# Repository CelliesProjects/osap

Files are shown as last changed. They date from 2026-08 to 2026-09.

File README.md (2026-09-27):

# OS Audio Player

ESP32 + VS1053 based network and SD audio player with a responsive web interface.

A very capable audio player with:

* MP3, M4A, AAC, OGG, and 16-bit FLAC playback
* Playlist queue for 100 items
* WebSocket based live UI
* A very fast **caching** SD card filebrowser
* Radio presets 
* Automatic adding of premium/private channels during build
* Internet radio search with [radio-browser.info](https://www.radio-browser.info/)
* Favorites system
* Mobile friendly interface

## OSAP UI video

https://github.com/user-attachments/assets/1be9de44-ba12-41da-8240-82e3cfe4a38c

## Finished player

assembled case

# Required hardware

Minimal component count, development is done on the following hardware:

* [7x9 cm prototype board](https://aliexpress.com/item/1005007977006793.html)
* [WEMOS S3 MINI](https://www.wemos.cc/en/latest/s3/s3_mini.html)
* [WEMOS Micro SD card shield](https://www.wemos.cc/en/latest/d1_mini_shield/micro_sd.html)
* [Adafruit VS1053 Codec + MicroSD Breakout](https://www.adafruit.com/product/1381)
* Optional [Adafruit 1.3" I²C OLED](https://www.adafruit.com/product/938) status indicator
* To connect the OLED a [STEMMA QT header cable](https://www.adafruit.com/product/4209)
* Web browser as main UI

The hardware listed above is the development/reference setup used for OSAP.  
Other ESP32-S3 boards, SD card interfaces and VS1053-based audio hardware may also be suitable.  
The software is not inherently tied to the specific boards listed here.

The reference player is build on the above 7x9 cm prototype board that fits the cases in the `stl` folder.

## Optional status indicator

An optional [Adafruit 1.3" I²C OLED display](https://www.adafruit.com/product/938) can be added for device status information.  

It displays boot progress, connection status and the current IP address.  

**Note:** To keep the player unobtrusive and power efficient, the OLED automatically sleeps after startup.  
Wake-up is performed using a capacitive touch input, which can be as simple as a GPIO connected to a metal button, screw head or other exposed conductive surface.

## SPI Configuration Notes

The current implementation assumes dedicated SPI buses for SD card and VS1053 access.  
Shared SPI configurations may compile, partially function, fully function or fail in creative and confusing ways.

Dedicated SPI wiring is the recommended and supported configuration.

---

# Features

## Privacy first

* No accounts
* No telemetry
* No phone app install
* No ads
* No “smart platform”
* Just a websocket UI on your LAN

## Audio 

* VS1053 hardware decoder with MP3, M4A, AAC, OGG and FLAC decoding
* Local SD playback
* Internet radio streaming
* Playlist queue system
* Favorites saving/loading
* Playback state synchronization between UI clients

## Web Interface

* Clean UI optimized for mobile use
* Responsive split-pane layout
* Works on all modern browsers
* Touch friendly controls
* Search interface for radio stations
* Overlay "now playing" mode
* Toast notifications and errors
* Very fast caching file browser

### Multiple WiFi networks supported

The player can be configured with multiple WiFi networks and automatically connects to the strongest available known network.  
This allows the same device to be used with different network setups such as a home network and a mobile phone hotspot without requiring reconfiguration.

## UI Performance

Multiple simultaneous clients are supported and kept in sync with the player state.  
SD requests are quite expensive and are handled async and cached to keep the UI responsive.  

- File browser requests are cached if the response takes more than 100 ms to build.  
- The favorites folder is cached on every mutation.  

---

# Download and initial setup

The following steps assume you already have a working VSCode/PlatformIO setup.

1. [Click here](https://github.com/CelliesProjects/osap/releases/latest) to go to the latest release page.  
On the release page, click on `Source code (zip)` then download and unzip this file.  

2. Open VSCode and select from the top menu `File->Open folder` then select the folder where you unzipped the repository to.  
This is the project folder.

3. Provide your wifi secrets by creating the file `src/secrets.hpp` in the project folder.  
See the [Building](#building) section below on how to format this file.

4. Open PlatformIO and select `Project tasks->develop->Upload and monitor`.  

PlatformIO will download and install all the assets that are needed to build the player firmware.  
This might take a while depending on your internet speed and computer capabilities.  
If all assets are installed, PlatformIO will start compiling and flash your player.

**Note:** The first time you build this project, a lot of files will be downloaded and then compiled which might take a long time.  

---

# Building the firmware

## Required secrets file

Before compiling create a new file with your WiFi and location secrets:

`src/secrets.hpp`

Use this example setup as a template:

```cpp
#pragma once

struct Secret
{
    const char *SSID;
    const char *PSK;
};

/* OSAP will connect to the strongest available network */
constexpr Secret networks[] =
    {
        {"network1", "password"},
        {"network2", "password"},
    };

/* Central European Time - see:
     https://github.com/nayarsystems/posix_tz_db/blob/master/zones.csv */
const char *TIMEZONE = "CET-1CEST,M3.5.0,M10.5.0/3";

/* Replace "nl" with your own country code:
    https://en.wikipedia.org/wiki/ISO_3166-2#Current_codes */
const char *NTP_POOL = "nl.pool.ntp.org";

/* Optional custom mDNS hostname */
//#define OSAP_HOSTNAME "music-player"
```

## Preset radio stations setup

Preset radio stations are defined in `src/presets.hpp`.

## Optional: adding private presets

Adding private or premium radio presets is very easy.

Place one or more `.pls` playlist files in the project root before compiling.  

During build:

* `.pls` files are automatically parsed
* presets are generated and merged into the main preset list

The added `.pls` files are ignored by git.

---

# Using the player

The web UI consists of two panes.  
A selectable source tab on the left and a playlist tab on the right.  

There are 4 source tabs, `library`, `presets`, `favorites` and `search`.

Click on a tab button to show a tab.

## Using the SD card library

You will need a FAT32 formatted micro SD card.  

Folders are navigated by clicking.

Single files can be added by clicking on the file or added and started with the **play** button.

Folders can be scanned and all found items added by clicking the **play** button.  

This will add all files in a folder and start playing the first added item if nothing is playing.  

## Favorites

Internet radio stations found through the search interface can be saved as favorites.

Favorites are stored on the SD card in the `/.favorites` folder.

Saved favorites can be inspected by visiting `http://player-ip/favorites` in a browser.

The generated files are formatted so they can easily be copied into `src/presets.hpp` if you want to make them permanent presets.

## Searching for radio stations

You can search for radio stations on [radio-browser.info](https://www.radio-browser.info/) with the search bar.  

Search results are displayed in the search tab.

## Now Playing overlay

The **Info** button at the bottom of the page toggles the *Now Playing* overlay.

The overlay shows the currently playing station or track and playback progress.  
After 30 seconds no activity the overlay is show automatically.  

When an Internet radio station originating from the search results is playing, a **Save as Favorite** button becomes available, allowing the station to be stored on the SD.

# Used Libraries / Components

## ESP32 C++ backend

These libraries are used internally by the player:

* HTTP traffic and WebSocket UI messaging are handled by [PsychicHttp](https://github.com/hoeken/PsychicHttp) webserver library - [MIT](https://github.com/hoeken/PsychicHttp?tab=MIT-1-ov-file)
* Audio playback is handled by [ESP32_VS1053_Stream](https://github.com/CelliesProjects/ESP32_VS1053_Stream) library - [MIT](https://github.com/CelliesProjects/ESP32_VS1053_Stream?tab=MIT-1-ov-file)
* Low level codec access is handled by [ESP_VS1053_Library](https://github.com/baldram/ESP_VS1053_Library) - [GPL-3.0](https://github.com/baldram/ESP_VS1053_Library?tab=GPL-3.0-1-ov-file)
* The OLED is handled by [Adafruit SSD1306 library](https://github.com/adafruit/Adafruit_SSD1306) - [BSD](https://github.com/adafruit/Adafruit_SSD1306?tab=License-1-ov-file)

## WebUI frontend

All frontend resources are compiled into the player UI:

* Vanilla HTML/CSS/JavaScript is used for the interface and application logic
* SVG icons from Google Fonts are inlined into the generated HTML during build - [Apache 2.0](https://github.com/google/material-design-icons?tab=Apache-2.0-1-ov-file#readme)
* [Reconnecting WebSocket](https://github.com/joewalnes/reconnecting-websocket) is included (minified) in the UI - [MIT](https://github.com/joewalnes/reconnecting-websocket?tab=MIT-1-ov-file)

---

# Building the hardware

Most of the required parts.  

parts

To stack the SD board on top of the CPU board, 3 pieces of [8 pin single row headers](https://aliexpress.com/item/1005011936791979.html) are required.

Also an additional countersunk M6 20-25mm long bolt with a fitting nut and a cable lug are required to build the example cases.

---

Possible parts layout, this layout will fit the cases in the `stl` folder and both cables and SD card are accesible.  
In this layout, the SD board is stacked on top of the CPU board and the default pins are used to save on wiring and assembly time.

layout

---

After wiring up and smoke testing.  
Connecting the case.

case inside

---

Testing touch and OLED.

touch and oled

---

The assembled player.

assembled case

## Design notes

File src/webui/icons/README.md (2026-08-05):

# OS Audio Player icons

The icons used in this app are downloaded from [fonts.google.com/icons](https://fonts.google.com/icons) and are [Apache 2.0](https://github.com/google/material-design-icons?tab=Apache-2.0-1-ov-file#readme) licensed.

Icon color = D9D9D9

example: https://fonts.google.com/icons?icon.size=24&icon.color=%23D9D9D9&icon.query=previous

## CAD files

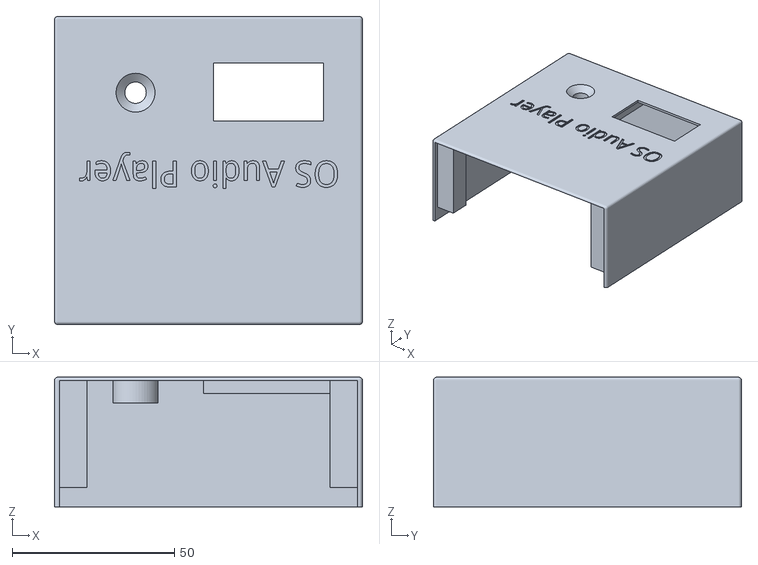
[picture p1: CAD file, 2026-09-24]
stl/OS Player base text.stl
95.0 x 95.0 x 40.0

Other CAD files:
stl/OS Player base.stl

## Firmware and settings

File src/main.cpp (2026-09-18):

#include <Arduino.h>
#include <WiFiMulti.h>
#include <Wire.h>
#include <SPI.h>
#include <SD.h>
#include <ESPmDNS.h>

#include "secrets.hpp"
#include "BrowserRequest.hpp"
#include "SearchRequest.hpp"
#include "FavoritesRequest.hpp"
#include "PlayerCmd.hpp"
#include "SystemState.hpp"
#include "gpio.hpp"

WiFiMulti wifiMulti;

SPIClass spiSD(HSPI);
SemaphoreHandle_t sdMutex = nullptr;
extern const char *FAVORITES_DIR;

QueueHandle_t playerQueue = nullptr;
QueueHandle_t browserQueue = nullptr;
QueueHandle_t searchQueue = nullptr;
QueueHandle_t favoritesQueue = nullptr;

extern void oledMessage(SystemState state, const char *msg);
extern void favoritesTask(void *param);
extern void oledTask(void *param);
extern void playerTask(void *param);
extern void serverTask(void *param);
extern void browserTask(void *param);
extern void searchTask(void *param);

#ifndef OSAP_HOSTNAME
#define OSAP_HOSTNAME "osap"
#endif

void runWiFiMulti()
{
    if (WiFi.status() != WL_CONNECTED)
    {
        log_i("WiFi not connected, reconnecting...");
        wifiMulti.run();
    }
}

static void setupMDNS()
{
    if (MDNS.begin(OSAP_HOSTNAME))
    {
        MDNS.addService("http", "tcp", 80);

        log_i("mdns started");

        return;
    }

    log_e("could not start mdns");
}

static void fatalError(const char *msg)
{
    log_e("FATAL ERROR! %s", msg);
    oledMessage(SystemState::ERROR, msg);
    delay(portMAX_DELAY);
}

static void createTask(TaskFunction_t fn, const char *name, uint32_t stack, UBaseType_t prio)
{
    if (xTaskCreate(fn, name, stack, nullptr, prio, nullptr) != pdPASS)
        fatalError(name);
}

static void setupNetworks()
{
    constexpr size_t NETWORK_COUNT = sizeof(networks) / sizeof(networks[0]);

    static_assert(NETWORK_COUNT > 0,
                  "At least one WiFi access point must be configured");

    static_assert(networks[0].SSID[0] != '\0',
                  "The first WiFi SSID may not be empty");

    wifiMulti.APlistClean();

    for (size_t curr = 0; curr < NETWORK_COUNT; curr++)
        wifiMulti.addAP(networks[curr].SSID, networks[curr].PSK);
}

void setup()
{
#if defined(CORE_DEBUG_LEVEL) && (CORE_DEBUG_LEVEL != ESP_LOG_NONE)
    Serial.begin(115200);

    log_i("Audioplayer version: %s", GIT_VERSION);
    log_i("ESP32 IDF Version %d.%d.%d", ESP_IDF_VERSION_MAJOR, ESP_IDF_VERSION_MINOR, ESP_IDF_VERSION_PATCH);
    log_i("ESP32 Arduino Version %d.%d.%d", ESP_ARDUINO_VERSION_MAJOR, ESP_ARDUINO_VERSION_MINOR, ESP_ARDUINO_VERSION_PATCH);
    log_i("CPU: %iMhz", getCpuFrequencyMhz());
#endif

    btStop(); /* switch off BlueTooth radio as it is not used in this app */

    Wire.setPins(OLED_SDA, OLED_SCL);
    Wire.begin();
    Wire.beginTransmission(OLED_BUS_ID);
    const uint8_t error = Wire.endTransmission();
    Wire.end(); /* allow Adafruit SSD1306 to reinitialize Wire cleanly */

    if (!error)
        createTask(oledTask, "oledTask", 4096, 0);

    browserQueue = xQueueCreate(5, sizeof(ListRequest));
    if (!browserQueue)
        fatalError("browser queue could not be created");

    playerQueue = xQueueCreate(10, sizeof(PlayerCmd));
    if (!playerQueue)
        fatalError("player queue could not be created");

    searchQueue = xQueueCreate(5, sizeof(SearchRequest));
    if (!searchQueue)
        fatalError("search queue could not be created");

    favoritesQueue = xQueueCreate(5, sizeof(FavoritesRequest));
    if (!favoritesQueue)
        fatalError("favorites queue could not be created");        

    sdMutex = xSemaphoreCreateMutex();
    if (!sdMutex)
        fatalError("sd mutex could not be created");

    if (!spiSD.begin(SD_SCK, SD_MISO, SD_MOSI))
        fatalError("sd spi pin error");

    if (!SD.begin(SD_CS, spiSD, 20000000))
    {
        log_e("card mount failed");
        oledMessage(SystemState::ERROR, "SD card not mounted");
    }
    else
        log_i("sd initialized");

    if (!SD.mkdir(FAVORITES_DIR))
        log_e("could not create %s", FAVORITES_DIR);

    WiFi.setAutoReconnect(false);
    WiFi.setSleep(false);

    setupNetworks();

    while (wifiMulti.run() != WL_CONNECTED)
        vTaskDelay(pdMS_TO_TICKS(3000));

    log_i("wifi connected to %s - ip: %s", WiFi.SSID().c_str(), WiFi.localIP().toString().c_str());

    configTzTime(TIMEZONE, NTP_POOL);

    struct tm timeinfo = {};
    while (!getLocalTime(&timeinfo, 0))
        delay(10);

    char buf[32];
    strftime(buf, sizeof(buf), "%Y-%m-%d %H:%M:%S", &timeinfo);

    log_i("ntp synced at %s local time", buf);

    setupMDNS();

    if (!SPI.begin(VS1053_SCK, VS1053_MISO, VS1053_MOSI))
        fatalError("vs1053 spi pin error");

    createTask(favoritesTask, "favoritesTask", 4096, 0);
    createTask(playerTask, "playerTask", 1024 * 5, 7);
    createTask(browserTask, "browserTask", 4096, 0);
    createTask(searchTask, "searchTask", 1024 * 5, 0);
    createTask(serverTask, "serverTask", 4096, 0);

    vTaskDelete(nullptr);
}

void loop()
{
}

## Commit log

2026-09-10 Improved: browserTask program flow (#28)
2026-09-17 Improved: favorite delete button behaviour (#45)
2026-09-18 Improved: favorite delete button behaviour (#47)
2026-09-24 Improved: show bufferstatus on UI (#53)
    [OS Player base.stl]
2026-09-24 Added: 7x9cm board case .stl files (#54)
    [OS Player base text.stl, OS Player base.stl]
2026-09-29 Improved: program flow (#68)
